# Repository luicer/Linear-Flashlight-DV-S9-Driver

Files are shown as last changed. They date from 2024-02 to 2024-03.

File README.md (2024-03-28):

# Driver Lineal for diving flashlight  DV-S9
Design of a variable linear driver for the DV-S9 diving flashlight, the driver is capable of handling currents of up to 3 A the  input voltage range is between  3V and 4.2V, and has low standby current. The driver achieves an efficiency of between 90% and 70% at maximum current. This design is open source hardware.

Teaser

Post where the design is esplained:
[https://luicer.github.io/led%20flashlight/Flashlight-Driver-Lineal-eng/](https://luicer.github.io/led%20flashlight/Flashlight-Driver-Lineal-eng/)

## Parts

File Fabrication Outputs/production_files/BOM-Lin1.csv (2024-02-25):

Comment | Designator | Footprint | LCSC
25 | R5 | R_0805_2012Metric_Pad1.20x1.40mm_HandSolder | C1015
100k | R9 | R_0805_2012Metric_Pad1.20x1.40mm_HandSolder | C149504
10n | C2,C7,C8 | R_0805_2012Metric_Pad1.20x1.40mm_HandSolder | C1710
1k | R10,R7,R8 | R_0805_2012Metric_Pad1.20x1.40mm_HandSolder | C1716
10k | R1 | R_0805_2012Metric_Pad1.20x1.40mm_HandSolder | C17414
120k | R12 | R_0805_2012Metric_Pad1.20x1.40mm_HandSolder | C17436
50k | R11 | R_0805_2012Metric_Pad1.20x1.40mm_HandSolder | C17470
80k | R4 | R_0805_2012Metric_Pad1.20x1.40mm_HandSolder | C17501
68k | R3 | R_0805_2012Metric_Pad1.15x1.40mm_HandSolder | C17801
22p | C5 | C_0805_2012Metric_Pad1.15x1.40mm_HandSolder | C1804
HT7130 | U5 | SOT-89-3 | C19162
1u | C4 | C_0805_2012Metric_Pad1.18x1.45mm_HandSolder | C28323
1n | C3 | C_0805_2012Metric_Pad1.15x1.40mm_HandSolder | C46653
0.01 | R6 | R_2512_6332Metric_Pad1.40x3.35mm_HandSolder | C571497
S9013 | Q1 | SOT-23 | C6749
IRLR2905 | Q2 | TO-252-3_TabPin2 | C68209
10u | C1,C6 | CP_EIA-3216-18_Kemet-A_Pad1.58x1.35mm_HandSolder | C7171
SGM8551XN | U2,U3,U4 | SOT-23-5 | C83748
SS49E | U1 | SS49E | C85697
100k | RV1 | TC33X-2-103E | C89235

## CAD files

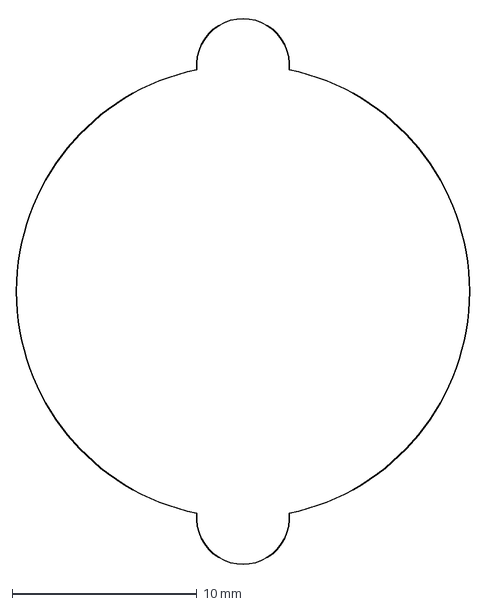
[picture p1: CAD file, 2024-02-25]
KICAD/Cut_edge1.dxf
24.5 x 29.8 mm

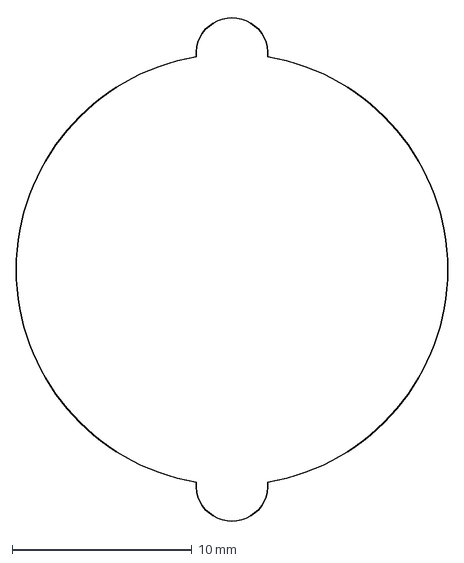
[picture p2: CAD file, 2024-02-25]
KICAD/Cut_edge.dxf
24.0 x 28.2 mm

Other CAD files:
KICAD/Cut_edge.dwg
KICAD/Cut_edge1.dwg

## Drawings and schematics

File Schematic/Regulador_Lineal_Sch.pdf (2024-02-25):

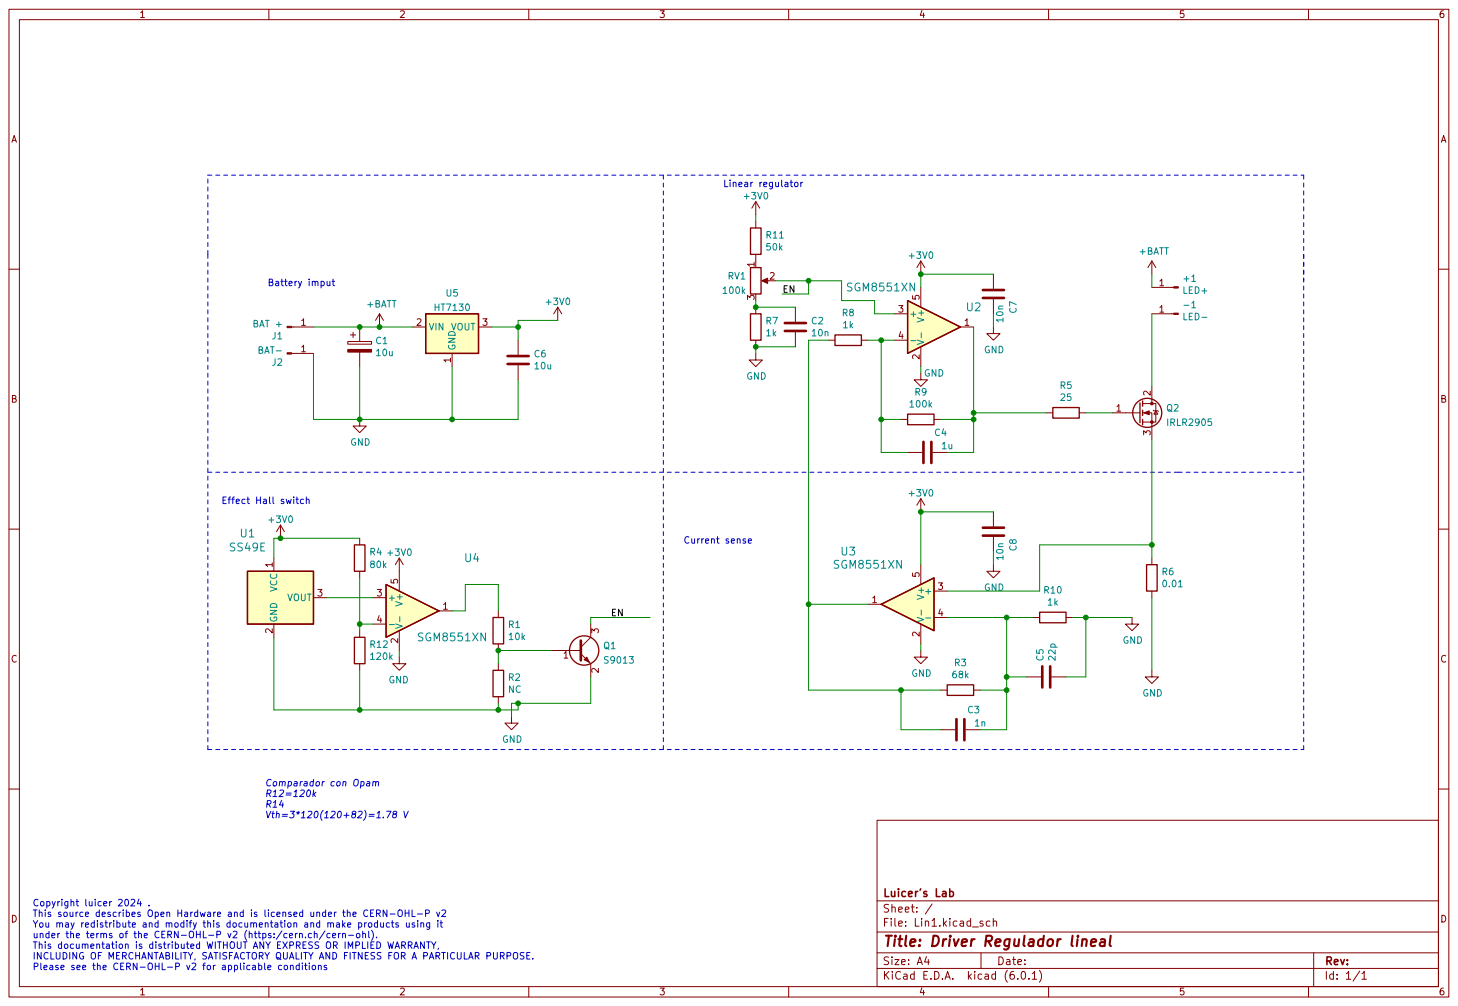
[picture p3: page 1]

Battery imput Effect Hall switch

Current sense Copyright luicer 2024 .

File: Lin1.kicad_sch Sheet: / Luicer's Lab R1

This source describes Open Hardware and is licensed under the CERN-OHL-P v2
You may redistribute and modify this documentation and make products using it
under the terms of the CERN-OHL-P v2 (https:/cern.ch/cern-ohl). This documentation is distributed WITHOUT ANY EXPRESS OR IMPLIED WARRANTY,

Id: 1/1 Title: Driver Regulador lineal

INCLUDING OF MERCHANTABILITY, SATISFACTORY QUALITY AND FITNESS FOR A PARTICULAR PURPOSE. Please see the CERN-OHL-P v2 for applicable conditions

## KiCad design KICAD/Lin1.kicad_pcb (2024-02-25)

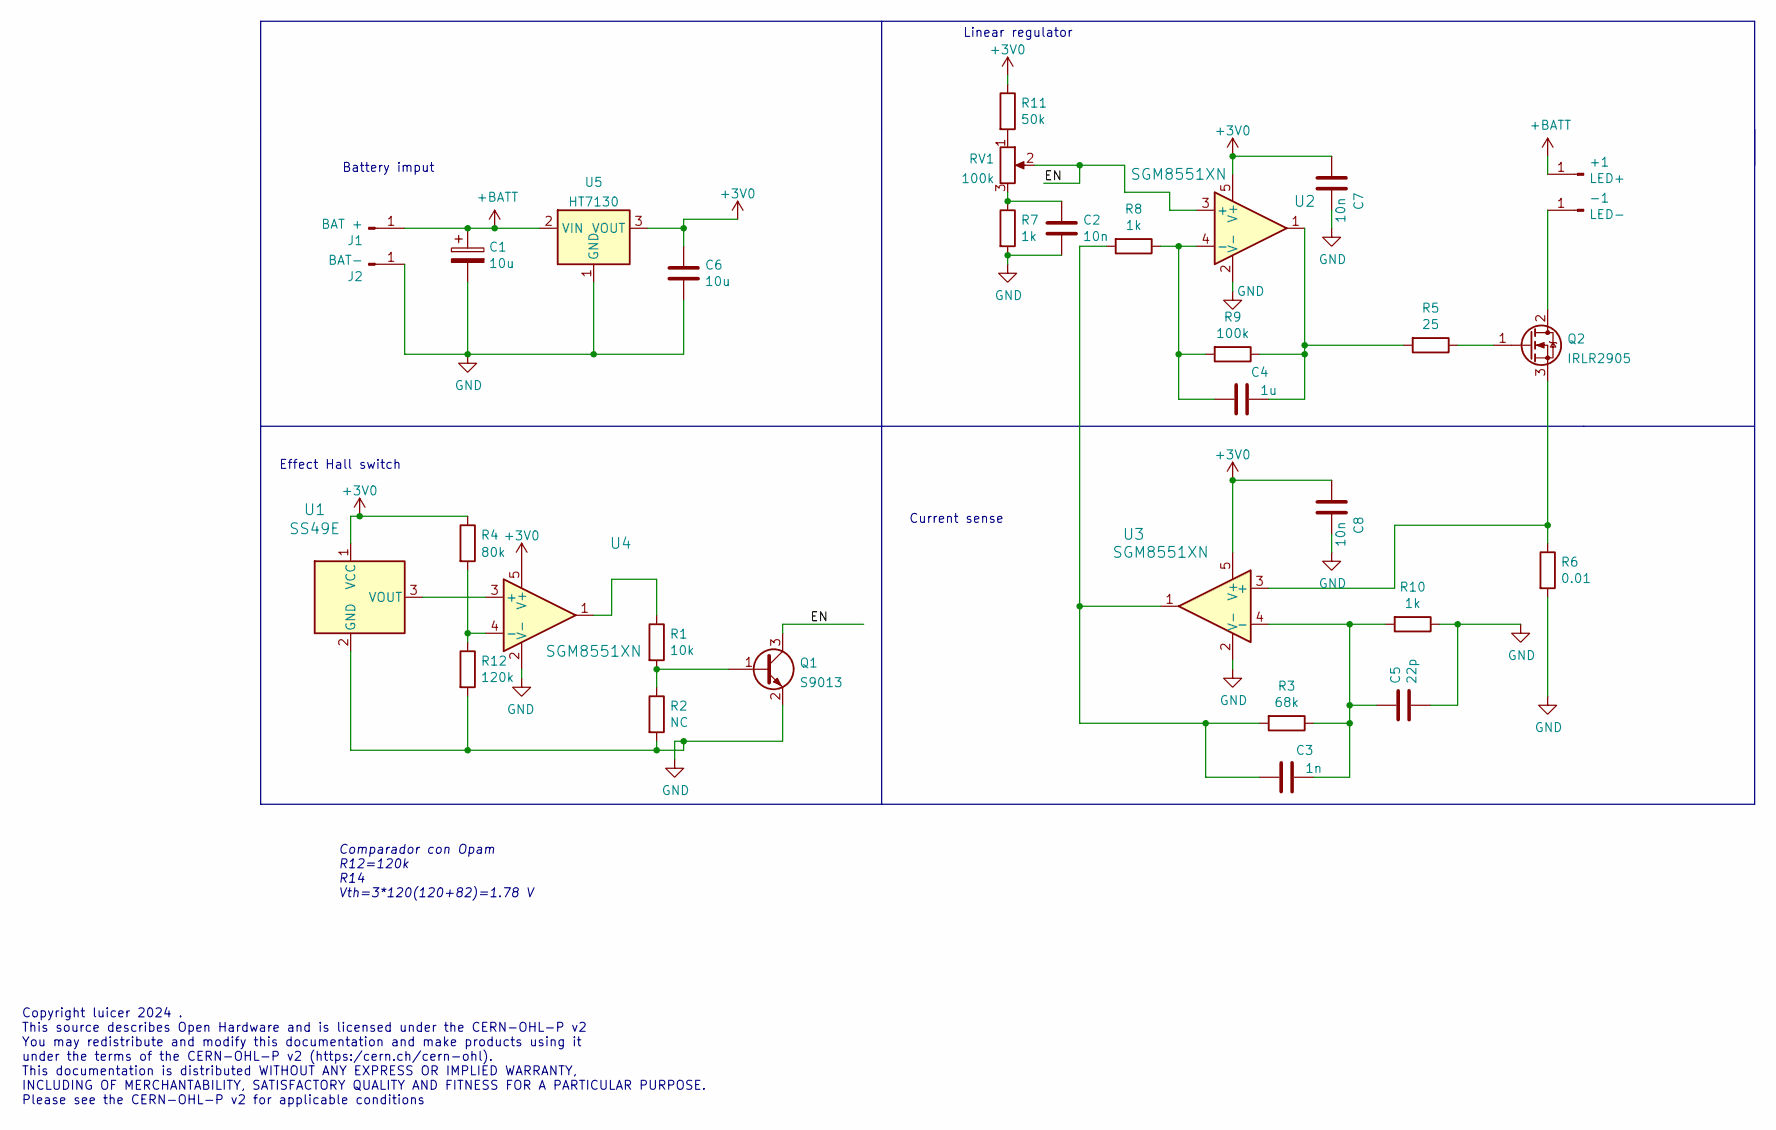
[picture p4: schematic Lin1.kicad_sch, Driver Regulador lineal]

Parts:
+1: LED+; Solder_Pad3_3
-1: LED-; Solder_Pad3_3
C1: 10u; CP_EIA-3216-18_Kemet-A_Pad1.58x1.35mm_HandSolder
C2: 10n; R_0805_2012Metric_Pad1.20x1.40mm_HandSolder
C3: 1n; C_0805_2012Metric_Pad1.15x1.40mm_HandSolder
C4: 1u; C_0805_2012Metric_Pad1.18x1.45mm_HandSolder
C5: 22p; C_0805_2012Metric_Pad1.15x1.40mm_HandSolder
C6: 10u; C_0805_2012Metric_Pad1.18x1.45mm_HandSolder
C7, C8: 10n; C_0805_2012Metric_Pad1.18x1.45mm_HandSolder
J1: BAT +; Lin_Pad+
J2: BAT-; Lin_Pad1-
Q1: S9013; SOT-23
Q2: IRLR2905; TO-252-3_TabPin2
R1: 10k; R_0805_2012Metric_Pad1.20x1.40mm_HandSolder
R2: NC; R_0805_2012Metric_Pad1.15x1.40mm_HandSolder
R3: 68k; R_0805_2012Metric_Pad1.15x1.40mm_HandSolder
R4: 80k; R_0805_2012Metric_Pad1.20x1.40mm_HandSolder
R5: 25; R_0805_2012Metric_Pad1.20x1.40mm_HandSolder
R6: 0.01; R_2512_6332Metric_Pad1.40x3.35mm_HandSolder
R7, R8, R10: 1k; R_0805_2012Metric_Pad1.20x1.40mm_HandSolder
R9: 100k; R_0805_2012Metric_Pad1.20x1.40mm_HandSolder
R11: 50k; R_0805_2012Metric_Pad1.20x1.40mm_HandSolder
R12: 120k; R_0805_2012Metric_Pad1.20x1.40mm_HandSolder
RV1: 100k; TC33X-2-103E
U1: SS49E
U2, U3, U4: SGM8551XN; SOT-23-5
U5: HT7130; SOT-89-3

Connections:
+3V0: C6.1, C7.2, C8.2, R4.1, R11.1, U1.1 (VCC), U2.5 (V+), U3.5 (V+), U4.5 (V+), U5.3 (VOUT)
+BATT: +1.1, C1.1, J1.1, U5.2 (VIN)
/EN: Q1.3 (C), RV1.2, U2.3 (+)
GND: C1.2, C2.2, C5.2, C6.2, C7.1, C8.1, J2.1, Q1.2 (E), R2.2, R6.2, R7.2, R10.1, R12.2, U1.2 (GND), U2.2 (V-), U3.2 (V-), U4.2 (V-), U5.1 (GND)
unnamed: -1.1, Q2.2 (D)
unnamed: C2.1, R7.1, RV1.3
unnamed: C3.1, C5.1, R3.1, R10.2, U3.4 (-)
unnamed: C3.2, R3.2, R8.2, U3.1
unnamed: C4.1, R5.2, R9.1, U2.1
unnamed: C4.2, R8.1, R9.2, U2.4 (-)
unnamed: Q1.1 (B), R1.2, R2.1
unnamed: Q2.1 (G), R5.1
unnamed: Q2.3 (S), R6.1, U3.3 (+)
unnamed: R1.1, U4.1
unnamed: R11.2, RV1.1
unnamed: R4.2, R12.1, U4.4 (-)
unnamed: U1.3 (VOUT), U4.3 (+)

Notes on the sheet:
Linear regulator
Copyright luicer 2024 . This source describes Open Hardware and is licensed under the CERN-OHL-P v2 You may redistribute and modify this documentation and make products using it under the terms of the CERN-OHL-P v2 (https:/cern.ch/cern-ohl). This documentation is distributed WITHOUT ANY EXPRESS OR 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
Battery imput
Effect Hall switch
Current sense
Comparador con Opam R12=120k R14 Vth=3*120(120+82)=1.78 V

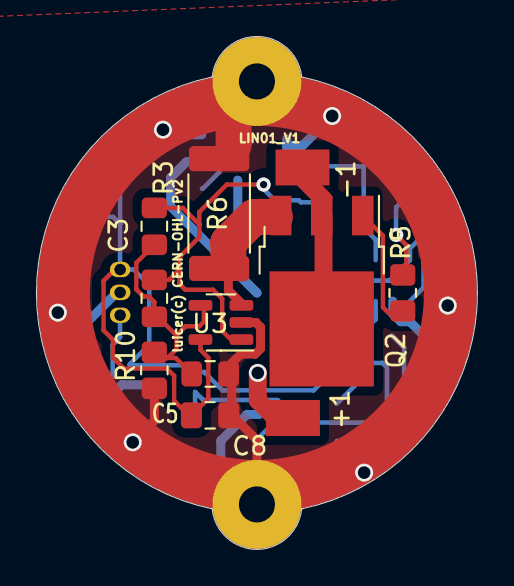
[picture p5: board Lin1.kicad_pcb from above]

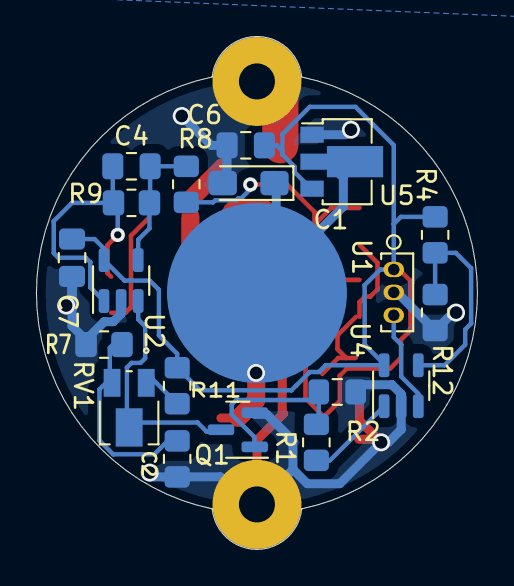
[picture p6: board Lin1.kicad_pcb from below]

Board: 2 copper layers, 24.5 x 28.5 mm, 32 parts (20 on the bottom side), 17 nets.

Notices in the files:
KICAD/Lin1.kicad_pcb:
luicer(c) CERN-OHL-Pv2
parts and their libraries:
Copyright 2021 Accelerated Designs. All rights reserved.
